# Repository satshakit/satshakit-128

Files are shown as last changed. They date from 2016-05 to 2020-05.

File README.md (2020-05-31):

<h1 style="font-family: courier;" align="center"> satshakit 128</h1>
<p align="center">
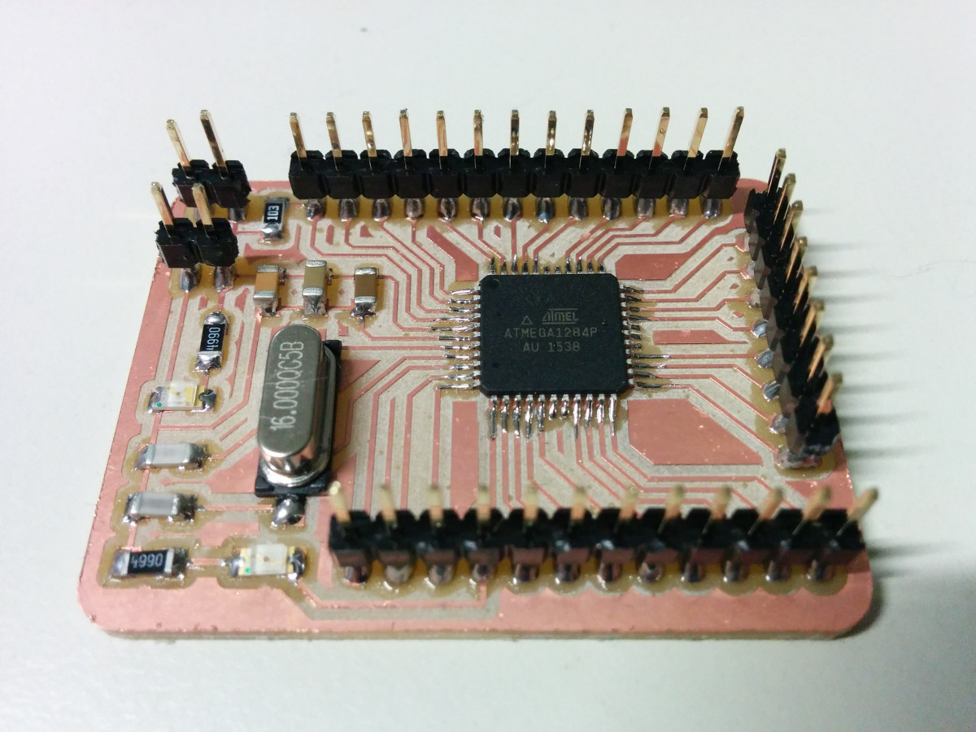
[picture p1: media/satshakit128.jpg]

<div align="center"><i>An improved & fabbable Arduino IDE/libraries compatible board.</i></div>
</p>  

What is satshakit?
--

satshakit is a **Arduino IDE  and libraries compatible**, fabbable and open source board, and also an improved version of [Fabkit](http://fabacademy.org/archives/2015/doc/projects/fabkit-0.4.html). 

Here you can find all of the satshakit boards: **[satshakit organization](https://github.com/satshakit)**.

satshakit 128
--

**satshakit 128** is microcontroller board designed around the **ATMega1284P** chip and it is suitable for complex scenarios in which is needed to have more flash and ram memory, but also the possibility to use 2 serial simultaneously.

In comparison with the other satshakits based on ATMega328P satshakit 128 has:

- **128k** flash memory instead of 32k
- **2 serials** instead of 1
- **16k of ram** instead of 2k
- **32 IO** pins instead of 23

Finally satshakit 128 is smaller than satshakit cnc and it costs **13 euro** each (much less for more).

Here you can have a look on **satshakit 128 board**:

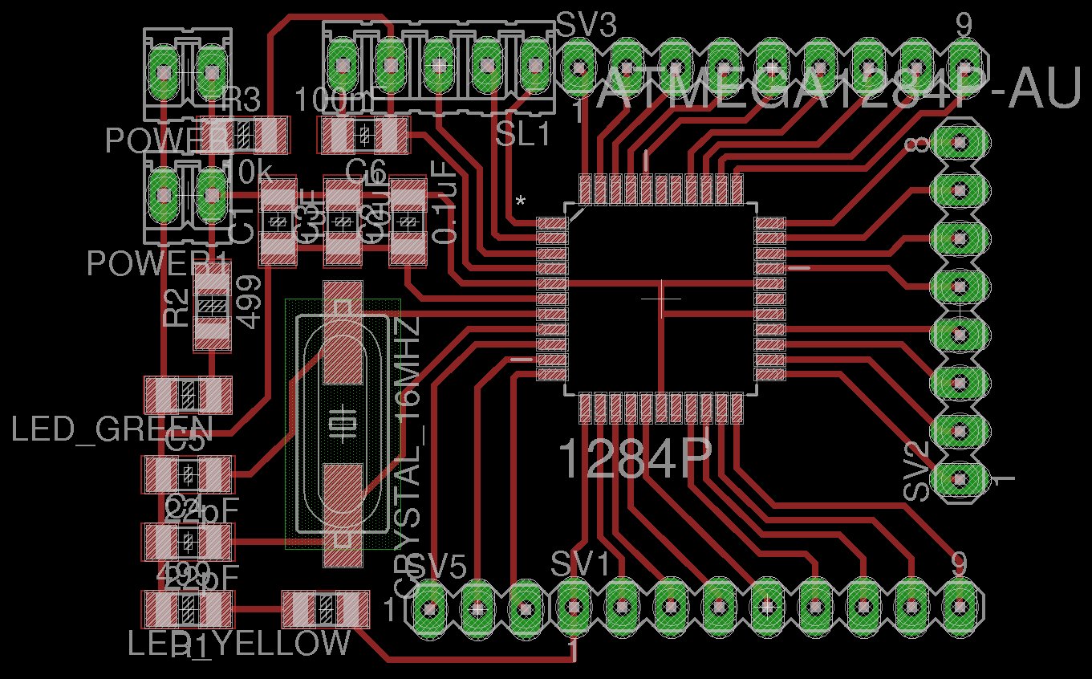
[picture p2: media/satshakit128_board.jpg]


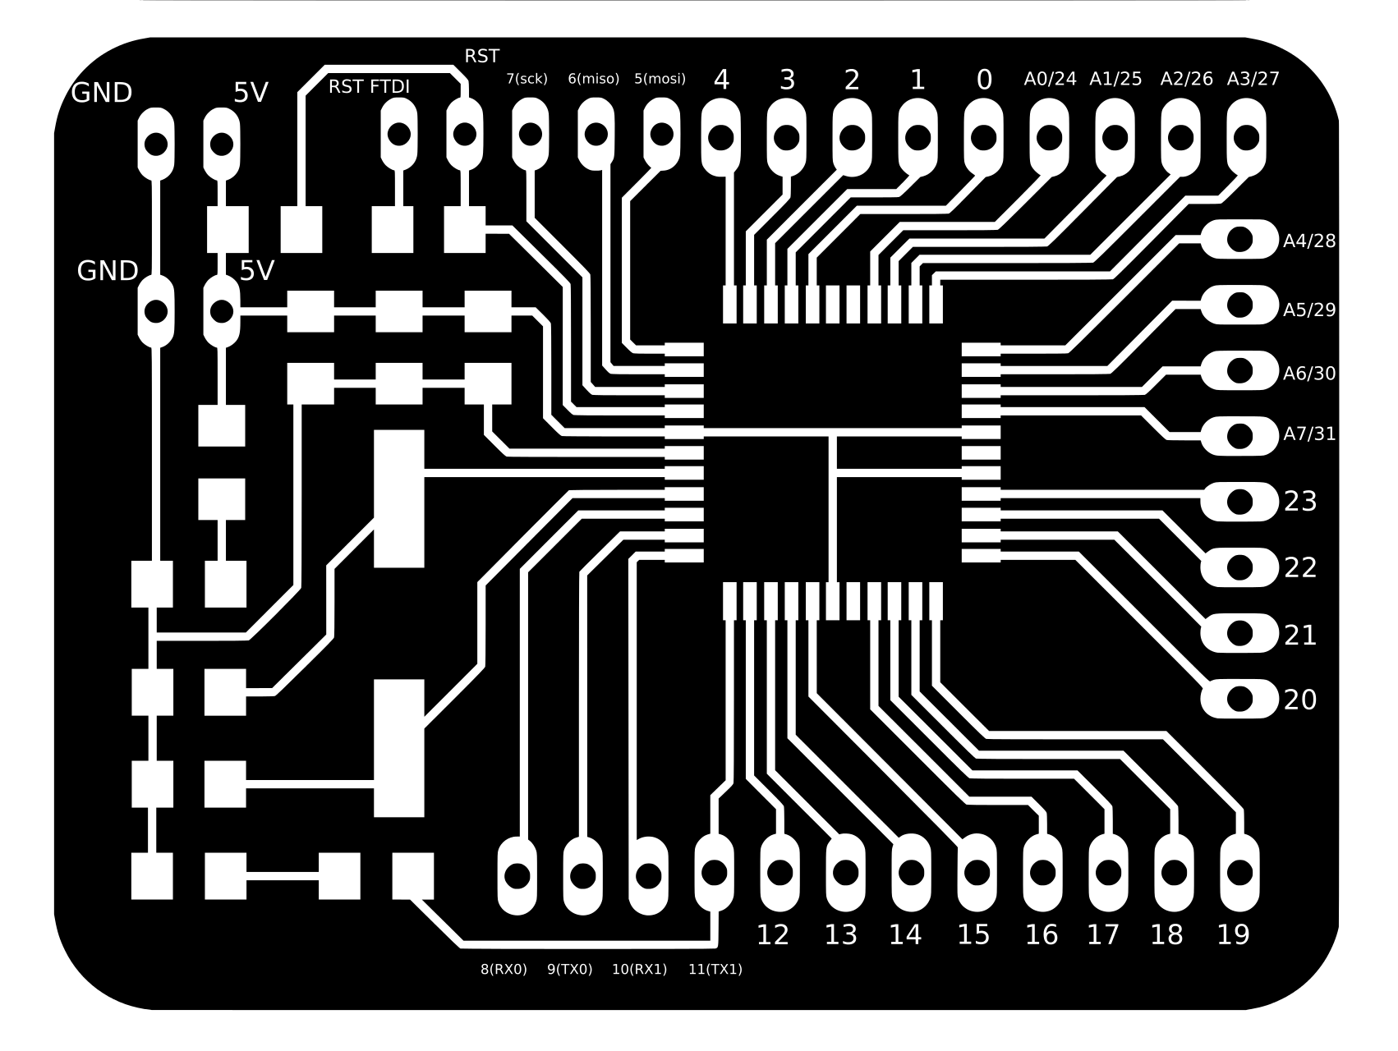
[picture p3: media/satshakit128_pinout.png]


**downloads (right click, download as)**

- [satshakit 128 svg](https://raw.githubusercontent.com/satshakit/satshakit-128/master/media/satshakit128.svg)
- [satshakit 128 internal png](https://raw.githubusercontent.com/satshakit/satshakit-128/master/media/satshakit128_internal.png)
- [satshakit 128 cut png](https://raw.githubusercontent.com/satshakit/satshakit-128/master/media/satshakit128_cut.png)
- [satshakit 128 schematic](https://raw.githubusercontent.com/satshakit/satshakit-128/master/eagle/satshakit128/satshakit128.sch)
- [satshakit 128 board](https://github.com/satshakit/satshakit-128/raw/master/eagle/satshakit128/satshakit128.brd)
- [satshakit 128 BOM Open Document](https://github.com/satshakit/satshakit-128/raw/master/docs/satshakit_128.ods)
- [satshakit 128 BOM Excel](https://github.com/satshakit/satshakit-128/raw/master/docs/satshakit_128.xlsx)

**media**

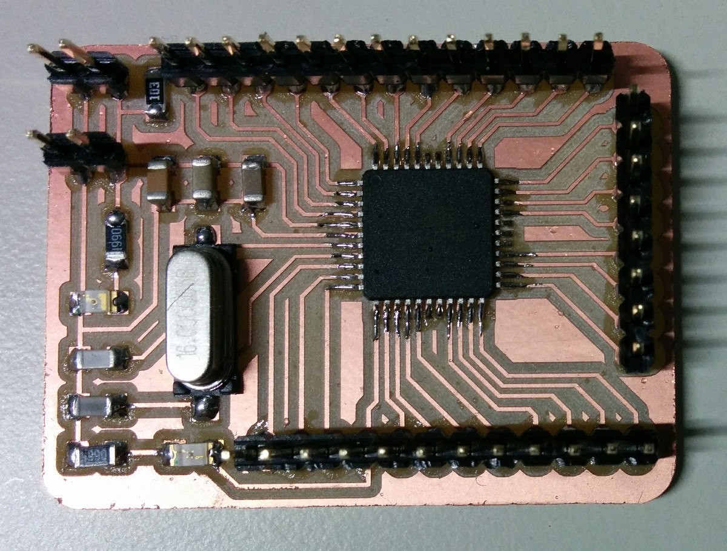
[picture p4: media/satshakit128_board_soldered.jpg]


satshakit 128 uploading bootloader:

<a href="http://www.youtube.com/watch?feature=player_embedded&v=KuCiwJ3c1IY
" target="_blank"></a>

satshakit 128 uploading blink:

<a href="http://www.youtube.com/watch?feature=player_embedded&v=X3d5tKupVwU
" target="_blank"></a>

Getting Started
--
A satshakit board is **very similar to an Arduino board**, thus is possible to use the Arduino IDE and its libraries. When you finish solder satshakit 128, you have to program it. If you want to use satshakit as an Arduino, you first need to **upload Arduino bootloader**. This will also set the ATmega1284P fuses. Before doing any programming you need to **patch your arduino IDE** using a specific set of files that will add the satshakit 128 as an available board to use. 

To add the support for satshakit 128 you can use the **[Mighty 1284P](https://github.com/JChristensen/mighty-1284p/tree/v1.6.3)**, that is provided in this repo inside the **[mighty-1284p folder](https://github.com/satshakit/satshakit-128/tree/master/mighty-1284p)**. 

To do so follow these steps:

1. **download** satshakit 128 repository
2. close **Arduino IDE** before doing anything
3. copy the folder named **mighty-1284p** inside the **Arduino IDE hardware folder**, **arduino-1.6.x/hardware/** in Linux, **Documents/Arduino/hardware** in MacOS 
4. open again the Arduino IDE
5. select **avr-developers.com pinouts 16MHz using Optiboot** board

Now you can use an Arduino as ISP to burn the bootloader and any Arduino sketch you want. To upload a program you connect **Arduino to the satshakit 128** as follows:

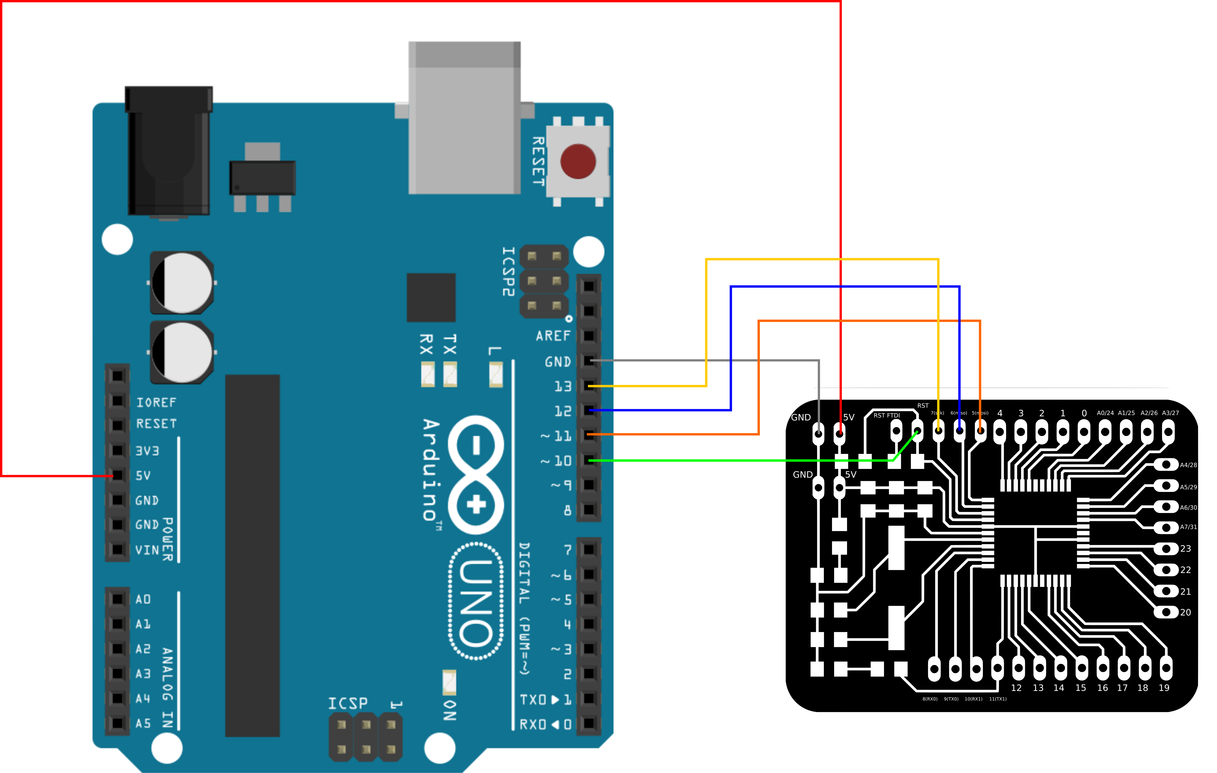
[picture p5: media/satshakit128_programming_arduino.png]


Once everything is connected, follow these steps to upload Arduino bootloader:

1. open Arduino IDE 
2. select proper programmer Arduino as ISP
3. select **avr-developers.com pinouts 16MHz using Optiboot** board
4. click on tools->Burn Bootloader

After you burnt the bootloader you can also use an **FTDI usb cable** to program the satshakit 128. Here is the connection schema to program the satshakit 128 using an FTDI cable:

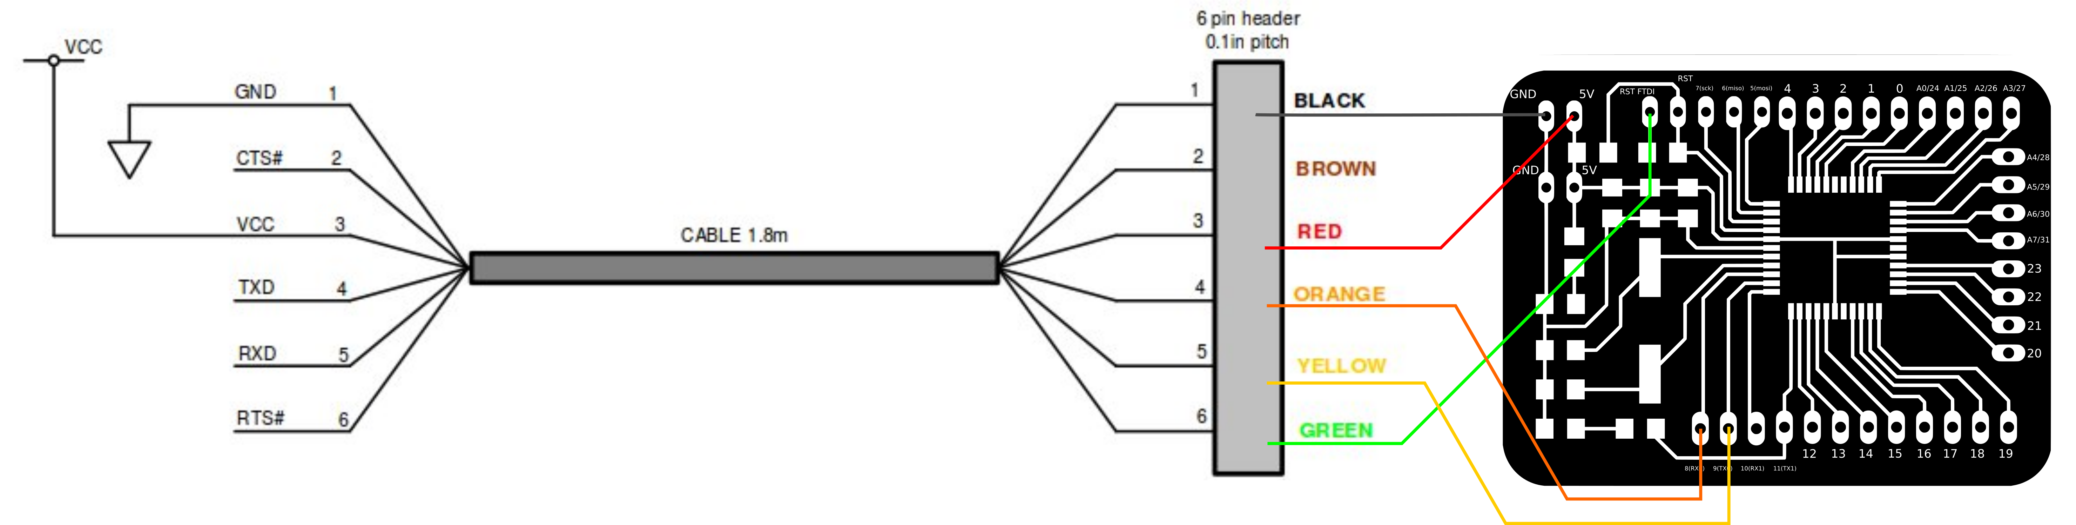
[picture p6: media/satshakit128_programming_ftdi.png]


Remember that if you try to program the satshakit 128 using an Arduino, then you will also delete the bootloader, losing the capability to be programmed using the FTDI cable. To hae back this possibility burn again the bootloader.

Here is the Arduino pinout of the satshakit 128:



What's in the repo
--
- **[docs](https://github.com/satshakit/satshakit-128/tree/master/docs)**: BOM files for Farnell
- **[egle projects](https://github.com/satshakit/satshakit-128/tree/master/eagle/satshakit128)**: eagle projects of satshakit
- **[media](https://github.com/satshakit/satshakit-128/tree/master/media)**: svg of satshakits, connections schemas, images for cnc milling machine and fiber laser cutter, other images

Authors
--

- Daniele Ingrassia

Contact
--

- **ingrassiada@gmail.com**
- **[linkedin](http://it.linkedin.com/in/danieleingrassia)**

Thanks
--

[Fablab Kamp-Lintfort](http://fablab.hochschule-rhein-waal.de/index.php/de/)<br />
Hochschule Rhein-Waal<br />
Friedrich-Heinrich-Allee 25, 47475 Kamp-Lintfort, Germany<br />
fablab@hochschule-rhein-waal.de

[Mighty 1284P](https://github.com/JChristensen/mighty-1284p/tree/v1.6.3)

License
--
This work is licensed under the terms of the open source license: Creative Commons Attribution-ShareAlike 4.0 International ([CC BY-SA 4.0](https://creativecommons.org/licenses/by-sa/4.0/)).

Disclaimer  
--

<div class="align-justify">
This hardware/software is provided "as is", and you use the hardware/software at your own risk. Under no circumstances shall any author be liable for direct, indirect, special, incidental, or consequential damages resulting from the use, misuse, or inability to use this hardware/software, even if the authors have been advised of the possibility of such damages.</div>

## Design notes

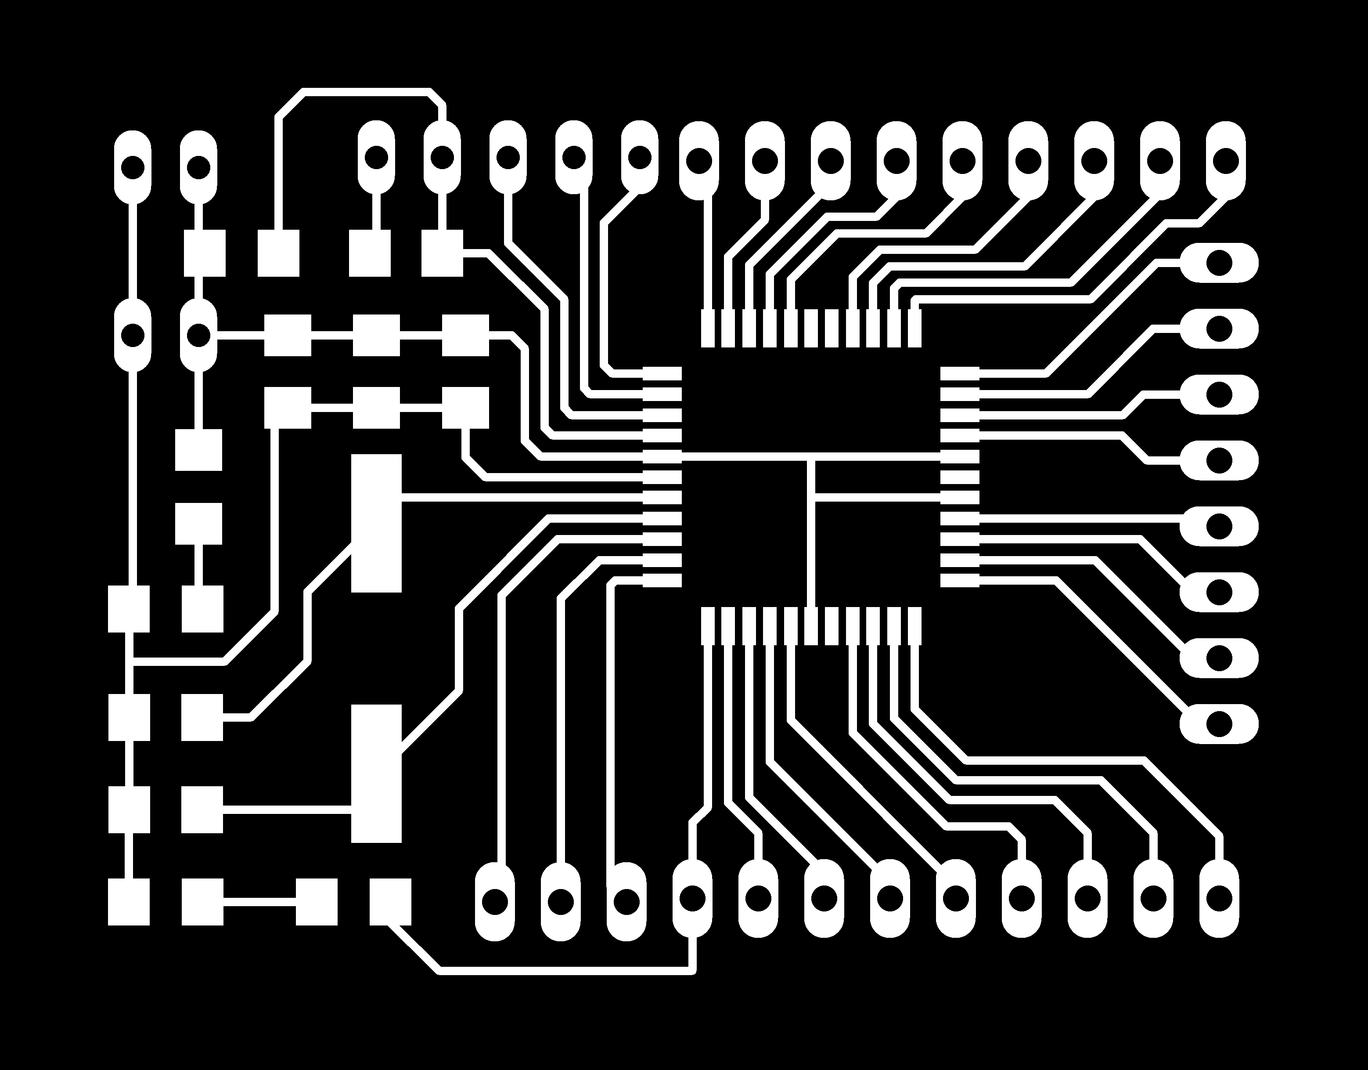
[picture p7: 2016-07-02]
media/satshakit128_internal.png

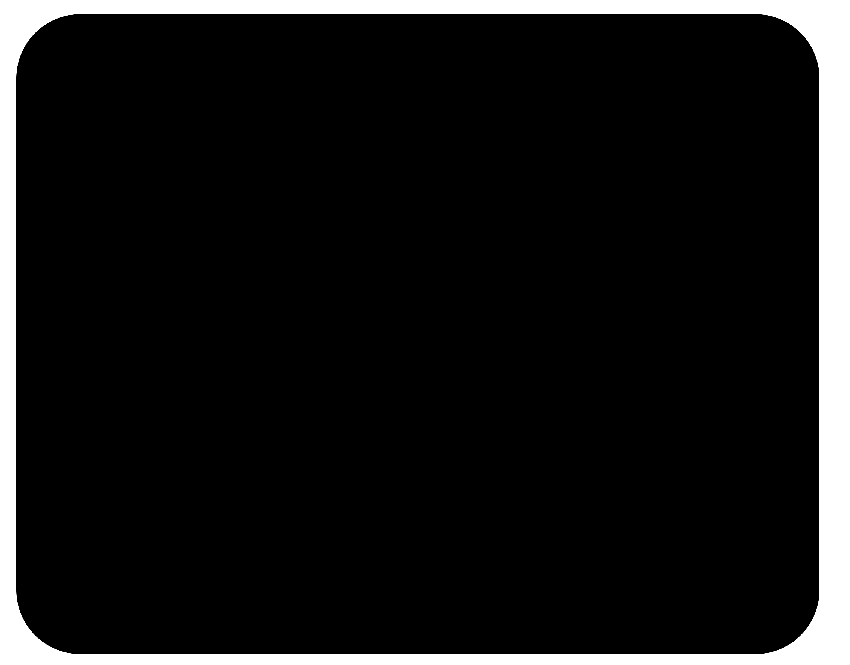
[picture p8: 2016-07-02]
media/satshakit128_cut.png

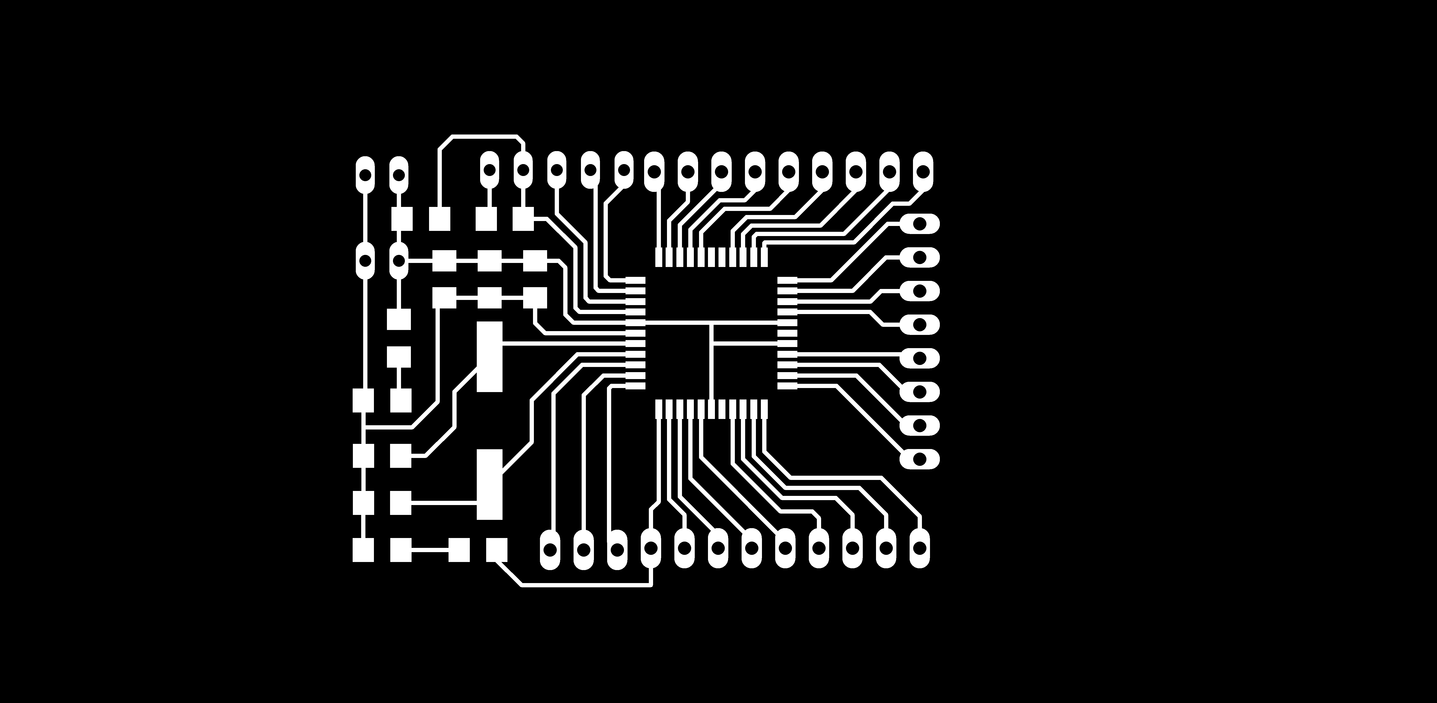
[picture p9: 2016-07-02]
media/satshakit128.png

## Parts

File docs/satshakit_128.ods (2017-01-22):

Value | Manufacturer Part No | Package | Description | FARNELL | Price € | Quantity | Min. Quantity Cost €
- | ATMEGA1284P-AU | TQFP-44 | microcontroller | 1715480 (http://it.farnell.com/atmel/atmega1284p-au/mcu-8bit-atmega-20mhz-tqfp-44/dp/1715480) | 7.56 | 1 | 7.56
16Mhz/18pF | MCRSD16000F183000RR | SMD 11.4 x 4.7 mm | crystal | 2395958 (http://it.farnell.com/multicomp/mcrsd16000f183000rr/crystal-16mhz-18pf-hc49-us-smd/dp/2395958) | 0.20 | 1 | 0.20
10K | ERJ8GEYJ103V | 1206 | resistor | 2057856 (http://it.farnell.com/panasonic-electronic-components/erj8geyj103v/resistore-1206-10k-5-0-25w/dp/2057856) | 0.03 | 1 | 0.26
22pF | MC1206N220J500CT | 1206 | capacitor | 2320891 (http://it.farnell.com/multicomp/mc1206n220j500ct/condens-mlcc-c0g-np0-22pf-50v/dp/2320891) | 0.05 | 2 | 0.47
10uF | MC1206X106K250CT | 1206 | capacitor | 2112753 (http://it.farnell.com/multicomp/mc1206x106k250ct/condensatore-mlcc-x5r-10uf-25v/dp/2112753) | 0.15 | 1 | 0.15
1uF | MC1206F105Z500CT | 1206 | capacitor | 1759455 (http://it.farnell.com/multicomp/mc1206f105z500ct/condensatore-mlcc-y5v-1uf-50v/dp/1759455) | 0.06 | 1 | 0.63
100nF | MC1206B104K500CT | 1206 | capacitor | 1759361 (http://it.farnell.com/multicomp/mc1206b104k500ct/condensatore-mlcc-x7r-100nf-50v/dp/1759361) | 0.04 | 2 | 0.70
green | MCL-S250GC | 1206 | green led | 1581232 (http://it.farnell.com/multicomp/mcl-s250gc/led-smd-1206-verde/dp/1581232) | 0.12 | 1 | 0.60
yellow | MCL-S250YC | 1206 | yellow led | 1581231 (http://it.farnell.com/multicomp/mcl-s250yc/led-smd-1206-giallo/dp/1581231) | 0.05 | 1 | 0.26
499 | CRCW1206499RFKEA | 1206 | resistor | 1470020 (http://it.farnell.com/vishay-draloric/crcw1206499rfkea/resistor-1206-499r-1/dp/1470020) | 0.03 | 2 | 0.28
- | 61304011021 | 2.54 mm | pin header | 2356192 (http://it.farnell.com/wurth-elektronik/61304011021/header-2-54mm-pin-tht-r-a-40way/dp/2356192) | 1.77 | 1 | 1.77
- | M20-9990246 | 2.54 mm | pin header | 1022247 (http://it.farnell.com/harwin/m20-9990246/header-diritta-2-54mm-1row-bifase/dp/1022247) | 0.07 | 1 | 0.65
 |  |  |  |  |  |  | Total cost
 |  |  |  |  |  |  | 13.54

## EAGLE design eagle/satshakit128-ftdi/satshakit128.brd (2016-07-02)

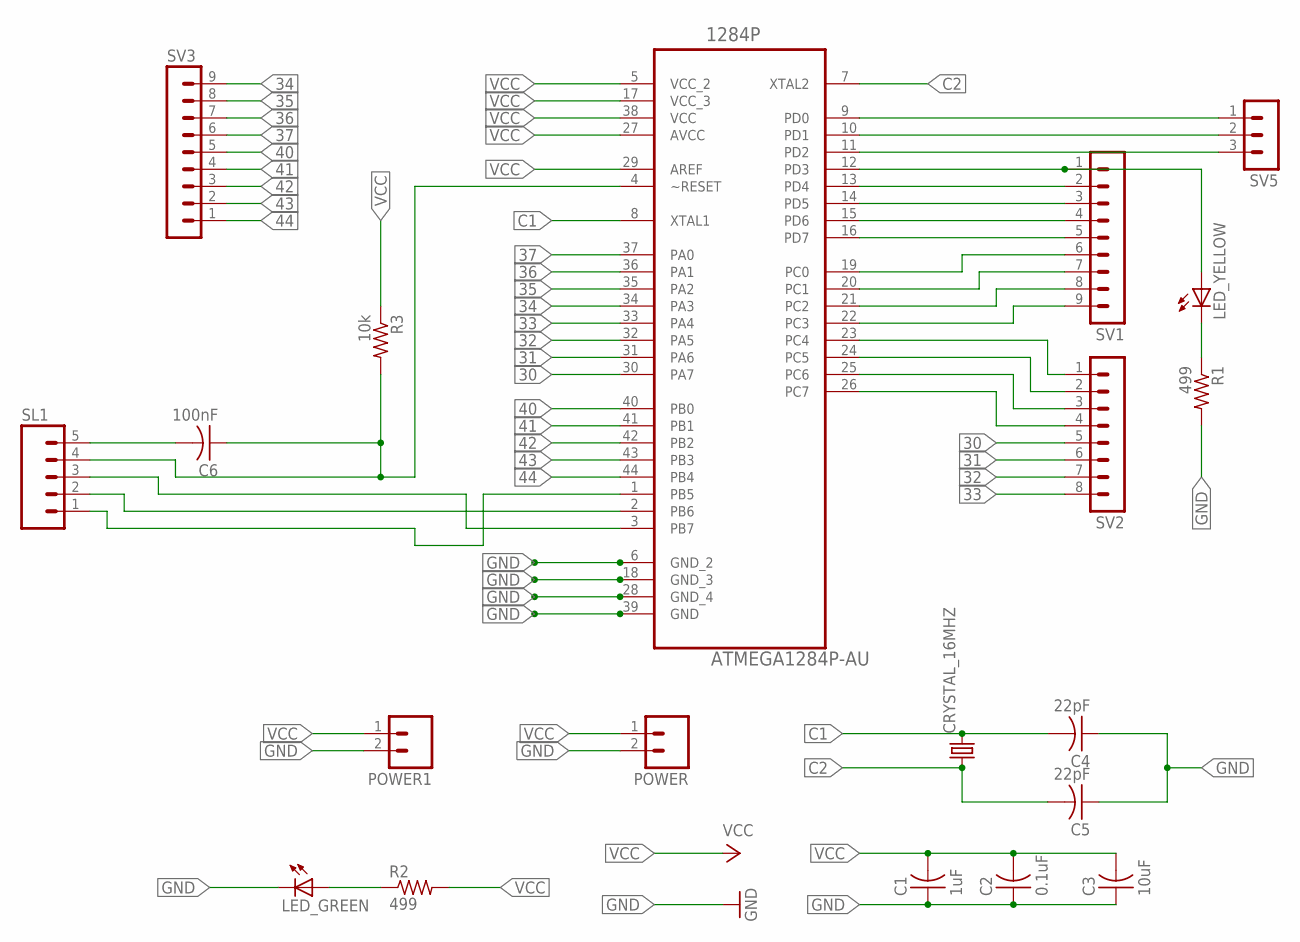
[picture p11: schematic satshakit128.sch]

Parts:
1284P: ATMEGA1284P-AU; QFP80P1200X1200X120-44N
C1: 1uF; C1206
C2: 0.1uF; C1206
C3: 10uF; C1206
C4, C5: 22pF; C1206
C6: 100nF; C1206
CRYSTAL_16MHZ: CRYSTALHC49UP; HC49UP
LED_GREEN: LED1206; 1206
LED_YELLOW: LED1206; 1206
POWER, POWER1: M02; 02P
R1, R2: 499; R1206
R3: 10k; R1206
SL1: M05; 05P
SV1, SV3: MA09-1
SV2: MA08-1
SV5: MA03-1

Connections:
30: 1284P.30 (PA7), SV2.5
31: 1284P.31 (PA6), SV2.6
32: 1284P.32 (PA5), SV2.7
33: 1284P.33 (PA4), SV2.8
34: 1284P.34 (PA3), SV3.9
35: 1284P.35 (PA2), SV3.8
36: 1284P.36 (PA1), SV3.7
37: 1284P.37 (PA0), SV3.6
40: 1284P.40 (PB0), SV3.5
41: 1284P.41 (PB1), SV3.4
42: 1284P.42 (PB2), SV3.3
43: 1284P.43 (PB3), SV3.2
44: 1284P.44 (PB4), SV3.1
C1: 1284P.8 (XTAL1), C4.2, CRYSTAL_16MHZ.2
C2: 1284P.7 (XTAL2), C5.2, CRYSTAL_16MHZ.1
GND: 1284P.6 (GND_2), C1.1, C2.1, C3.1, C4.1, C5.1, LED_GREEN.2 (C), POWER.2, POWER1.2, R1.2
unnamed: 1284P.19 (PC0), SV1.6
unnamed: 1284P.20 (PC1), SV1.7
unnamed: 1284P.16 (PD7), SV1.5
unnamed: 1284P.14 (PD5), SV1.3
unnamed: 1284P.13 (PD4), SV1.2
unnamed: 1284P.12 (PD3), LED_YELLOW.1 (A), SV1.1
unnamed: 1284P.11 (PD2), SV5.3
unnamed: 1284P.10 (PD1), SV5.2
unnamed: 1284P.9 (PD0), SV5.1
unnamed: 1284P.21 (PC2), SV1.8
unnamed: 1284P.22 (PC3), SV1.9
unnamed: 1284P.23 (PC4), SV2.1
unnamed: 1284P.24 (PC5), SV2.2
unnamed: 1284P.25 (PC6), SV2.3
unnamed: 1284P.26 (PC7), SV2.4
unnamed: 1284P.15 (PD6), SV1.4
unnamed: 1284P.3 (PB7), SL1.3
unnamed: 1284P.2 (PB6), SL1.2
unnamed: 1284P.1 (PB5), SL1.1
unnamed: 1284P.4 (~RESET), C6.1, R3.2, SL1.4
unnamed: LED_YELLOW.2 (C), R1.1
unnamed: LED_GREEN.1 (A), R2.1
unnamed: C6.2, SL1.5
VCC: 1284P.5 (VCC_2), 1284P.17 (VCC_3), 1284P.27 (AVCC), 1284P.29 (AREF), C1.2, C2.2, C3.2, POWER.1, POWER1.1, R2.2, R3.1

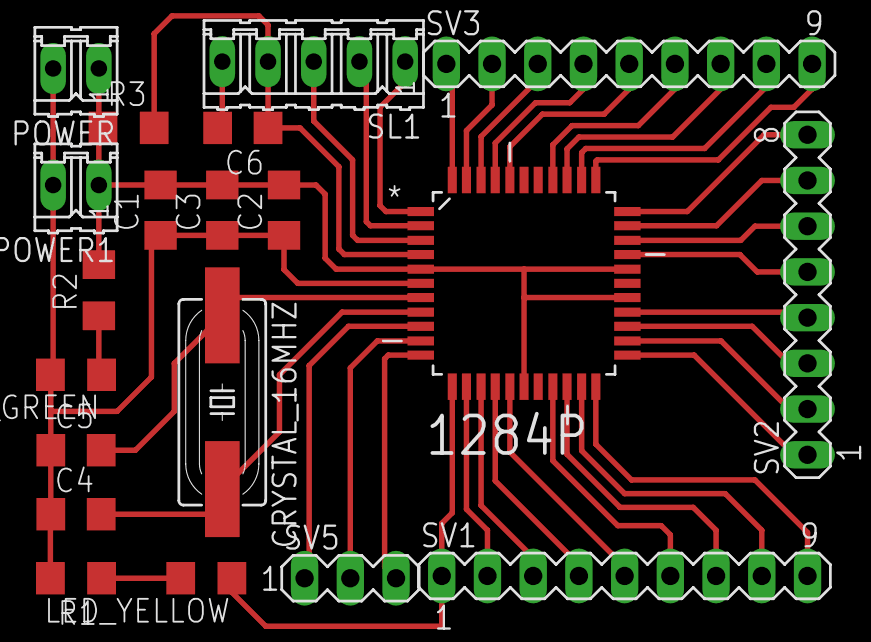
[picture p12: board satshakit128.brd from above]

Board: 2 copper layers, 20 parts (0 on the bottom side), 40 nets.

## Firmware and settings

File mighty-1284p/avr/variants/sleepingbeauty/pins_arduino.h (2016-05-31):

#ifndef Pins_Arduino_h
#define Pins_Arduino_h

#include <avr/pgmspace.h>

// Turn on this define when setting jumpers
// to use A4 and A5 for i2c vs analog pins
// See FootNote below for details
//#define _SB_BOARD_A4A5_I2C

// note: this define can be automatically be turned on through a menu entry
// in the boards.txt file by using the build extra_flags capability.
// i.e. using build.extra_flags=-D_SB_BOARD_A4A5_I2C

// ATMEL ATMEGA1284P on Sleeping Beauty board
//
//                            +---\/---+
//                (D 4) PB0 1 |        | 40 PA0 (D 21) AI 0
//                (D 5) PB1 2 |        | 39 PA1 (D 20) AI 1
//           INT2 (D 6) PB2 3 |        | 38 PA2 (D 19) AI 2
//       PWM/OC0A (D 7) PB3 4 |        | 37 PA3 (D 18) AI 3
//   PWM/OC0B/SS (D 10) PB4 5 |        | 36 PA4 (D 17) AI 4  *
//          MOSI (D 11) PB5 6 |        | 35 PA5 (D 16) AI 5  *
// PWM/OC3A/MISO (D 12) PB6 7 |        | 34 PA6 (D 30) AI 6
//  PWM/OC3B/SCK (D 13) PB7 8 |        | 33 PA7 (D 31) AI 7
//                      RST 9 |        | 32 AREF
//                     VCC 10 |        | 31 GND 
//                     GND 11 |        | 30 AVCC
//                   XTAL2 12 |        | 29 PC7 (D 14) 
//                   XTAL1 13 |        | 28 PC6 (D 15) 
//           RX0 (D 0) PD0 14 |        | 27 PC5 (D 27) TDI
//           TX0 (D 1) PD1 15 |        | 26 PC4 (D 26) TDO
//      INT0 RX1 (D 2) PD2 16 |        | 25 PC3 (D 25) TMS
//      INT1 TX1 (D 3) PD3 17 |        | 24 PC2 (D 24) TCK
//     PWM/OC1B (D 22) PD4 18 |        | 23 PC1 (D 28) SDA  *
//      PWM/OC1A (D 9) PD5 19 |        | 22 PC0 (D 29) SCL  *
//      PWM/OC2B (D 8) PD6 20 |        | 21 PD7 (D 23) PWM/OC2A
//                            +--------+
//
// *NOTE:
// Some boards contain a pair of jumpers which control A4 and A5 labeled pins.
// The Sleeping Beauty uses J4 and the BareBones boards use H5.
// The jumpers control which 1284 pins are physically connected to
// the pins labeled A4 and A5 on the board.
// When in the "deault"/"analog" or up position, the A4 and A5 labeled pins are
// connected to 1284 pins 35 and 35 which allows them to be used as analog
// inputs or digital pins using the A4 and A5 symbols in this header file.
//
// If the jumpers are in the "i2c" or down position, the A4 and A4 labeled
// pins are connected to 1284 pins 22 and 23 which is SCL and SDA.
// This allows the pins to be used for i2c or digital i/o but not for analog
// read operations.
// When jumpers are in this position, the symbols for A4 and A4 will not
// be correct unless the define above is also turned on.
//
/*
 *===========================================================================
 *
 * One of the major simplifications implemented by the Arduino core
 * libraries is the ability to reference the IO pins by a BOARD-defined "Pin
 * number" rather than needing to deal with the various IO register
 * addresses and bit numbers or masks that microcontrollers normally use to
 * access the external world.
 *
 * Of course, at some point the functions that use the "pin number" need to
 * translate that abstraction into the actual IO address and bits need to
 * manipulate them.  This is accomplished by core code in wiring_*.c that is
 * essentially identical for each major chip architecture (ie "avr"), and
 * this pins_arduino.h file that contains the specifics on a per-board or
 * per-chip basis.
 *
 * Various algorithms are possible, and there can be significant differences
 * depending on the capabilities of the architecture and chip being
 * used. (for example, a PIC32 has separate Set and Clear IO registers for
 * bitwise access, and an ARM CM3 might use "bit-banding")
 *

 * variants/<boarddesc>/pins_arduino.h contains the macros and/or tables
 * used to convert from Arduino-style "pin numbers" (0-13 on Uno, for
 * example) to the internal information necessary to perform operations on
 * those pins.
 *
 *===========================================================================
*/


/*
 * Most AVR-based Arduinos use tables built into flash (program) memory to
 * do the bulk of work, so we'll need the avr-libc definitions for dealing
 * with this additional address space.
 */

 
/*
 * Total number of digital pins.  This includes any analog pins that could
 * also be used for digital IO.
 */

#define NUM_DIGITAL_PINS            32

/*
 * Total number of Analog Input pins
 */

#define NUM_ANALOG_INPUTS           8


/*
 * Mapping macros
 * Some of these have to change depending on the board jumpers
 */
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

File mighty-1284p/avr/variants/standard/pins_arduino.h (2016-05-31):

#ifndef Pins_Arduino_h
#define Pins_Arduino_h

#include <avr/pgmspace.h>

// ATMEL ATMEGA1284P
//
//                       +---\/---+
//           (D 0) PB0  1|        |40  PA0 (AI 0 / D24)
//           (D 1) PB1  2|        |39  PA1 (AI 1 / D25)
//      INT2 (D 2) PB2  3|        |38  PA2 (AI 2 / D26)
//       PWM (D 3) PB3  4|        |37  PA3 (AI 3 / D27)
//    PWM/SS (D 4) PB4  5|        |36  PA4 (AI 4 / D28)
//      MOSI (D 5) PB5  6|        |35  PA5 (AI 5 / D29)
//  PWM/MISO (D 6) PB6  7|        |34  PA6 (AI 6 / D30)
//   PWM/SCK (D 7) PB7  8|        |33  PA7 (AI 7 / D31)
//                 RST  9|        |32  AREF
//                 VCC 10|        |31  GND 
//                 GND 11|        |30  AVCC
//               XTAL2 12|        |29  PC7 (D 23)
//               XTAL1 13|        |28  PC6 (D 22)
//      RX0 (D 8)  PD0 14|        |27  PC5 (D 21) TDI
//      TX0 (D 9)  PD1 15|        |26  PC4 (D 20) TDO
// RX1/INT0 (D 10) PD2 16|        |25  PC3 (D 19) TMS
// TX1/INT1 (D 11) PD3 17|        |24  PC2 (D 18) TCK
//      PWM (D 12) PD4 18|        |23  PC1 (D 17) SDA
//      PWM (D 13) PD5 19|        |22  PC0 (D 16) SCL
//      PWM (D 14) PD6 20|        |21  PD7 (D 15) PWM
//                       +--------+
//

/*
   PCINT15-8: D7-0  : bit 1
   PCINT31-24: D15-8  : bit 3
   PCINT23-16: D23-16 : bit 2
   PCINT7-0: D31-24   : bit 0
   */

#define MIGHTY_1284P_VARIANT "STANDARD"

#define NUM_DIGITAL_PINS            32
#define NUM_ANALOG_INPUTS           8
#define analogInputToDigitalPin(p)  ( (p) < NUM_ANALOG_INPUTS ? (p) + 24 : -1 )
#define digitalPinToAnalogPin(p)    ( (p) >= 24 && (p) <= 31 ? (p) - 24 : -1 )
#define analogPinToChannel(p)       ( (p) < NUM_ANALOG_INPUTS ? (p) : (p) >= 24 ? (p) - 24 : -1 )    //required macro for mighty-1284p core
#define digitalPinHasPWM(p)         ( (p) == 3 || (p) == 4 || (p) == 6 || (p) == 7 || (p) == 12 || (p) == 13 || (p) == 14 || (p) == 15 )

static const uint8_t SS   = 4;
static const uint8_t MOSI = 5;
static const uint8_t MISO = 6;
static const uint8_t SCK  = 7;

static const uint8_t SDA = 17;
static const uint8_t SCL = 16;
static const uint8_t LED_BUILTIN = 7;

static const uint8_t A0 = 24;
static const uint8_t A1 = 25;
static const uint8_t A2 = 26;
static const uint8_t A3 = 27;
static const uint8_t A4 = 28;
static const uint8_t A5 = 29;
static const uint8_t A6 = 30;
static const uint8_t A7 = 31;

#define digitalPinToPCICR(p)    ( (p) >= 0 && (p) < NUM_DIGITAL_PINS ? &PCICR : (uint8_t *)0 )
#define digitalPinToPCICRbit(p) ( (p) <= 7 ? 1 : (p) <= 15 ? 3 : (p) <= 23 ? 2 : 0 )
#define digitalPinToPCMSK(p)    ( (p) <= 7 ? &PCMSK1 : (p) <= 15 ? &PCMSK3 : (p) <= 23 ? &PCMSK2 : &PCMSK0 )
#define digitalPinToPCMSKbit(p) ( (p) % 8 )
// return associated INTx number for associated/valid pins,
// otherwise NOT_AN_INTERRUPT
#define digitalPinToInterrupt(p) \
	(\
	(p) == 10 ? 0 : \
	(p) == 11 ? 1 : \
	(p) == 2 ? 2 : \
	NOT_AN_INTERRUPT)


#define PA 1
#define PB 2
#define PC 3
#define PD 4

// specify port for each pin D0-D31
#define PORT_D0 PB
#define PORT_D1 PB
#define PORT_D2 PB
#define PORT_D3 PB
#define PORT_D4 PB
#define PORT_D5 PB
#define PORT_D6 PB
#define PORT_D7 PB
#define PORT_D8 PD
#define PORT_D9 PD
#define PORT_D10 PD
#define PORT_D11 PD
#define PORT_D12 PD
#define PORT_D13 PD
#define PORT_D14 PD
#define PORT_D15 PD
#define PORT_D16 PC
#define PORT_D17 PC
#define PORT_D18 PC
#define PORT_D19 PC
#define PORT_D20 PC
#define PORT_D21 PC
#define PORT_D22 PC
#define PORT_D23 PC
#define PORT_D24 PA
#define PORT_D25 PA
#define PORT_D26 PA
#define PORT_D27 PA
#define PORT_D28 PA
#define PORT_D29 PA
#define PORT_D30 PA
#define PORT_D31 PA

// specify port bit for each pin D0-D31
#define BIT_D0 0
#define BIT_D1 1
#define BIT_D2 2
#define BIT_D3 3
#define BIT_D4 4
#define BIT_D5 5
#define BIT_D6 6
#define BIT_D7 7
#define BIT_D8 0
#define BIT_D9 1
#define BIT_D10 2
#define BIT_D11 3
#define BIT_D12 4
#define BIT_D13 5
#define BIT_D14 6
#define BIT_D15 7
#define BIT_D16 0
#define BIT_D17 1
#define BIT_D18 2
#define BIT_D19 3
#define BIT_D20 4
#define BIT_D21 5
#define BIT_D22 6
#define BIT_D23 7
#define BIT_D24 0
#define BIT_D25 1
#define BIT_D26 2
#define BIT_D27 3
#define BIT_D28 4
#define BIT_D29 5
#define BIT_D30 6
#define BIT_D31 7

// macro equivalents of PROGMEM arrays port_to_mode_PGM[] etc. below
#define PORT_TO_MODE(x) (x == 1 ? &DDRA : (x == 2 ? &DDRB : (x == 3 ? &DDRC : (x == 4 ? &DDRD : NOT_A_PORT)))) 
#define PORT_TO_OUTPUT(x) (x == 1 ? &PORTA : (x == 2 ? &PORTB : (x == 3 ? &PORTC : (x == 4 ? &PORTD : NOT_A_PORT))))
#define PORT_TO_INPUT(x) (x == 1 ? &PINA : (x == 2 ? &PINB : (x == 3 ? &PINC : (x == 4 ? &PIND : NOT_A_PORT)))) 
 
#ifdef ARDUINO_MAIN
// these arrays map port names (e.g. port B) to the
// appropriate addresses for various functions (e.g. reading
// and writing)
const uint16_t PROGMEM port_to_mode_PGM[] =
{
  NOT_A_PORT,
  (uint16_t) &DDRA,
  (uint16_t) &DDRB,
  (uint16_t) &DDRC,
  (uint16_t) &DDRD,
};
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

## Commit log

2016-05-31 first satshakit128 commit
    [pins.ods, satshakit128.brd, satshakit128.sch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]
2016-07-02 added a new version that is possible to proigram using only the FTDI
    [satshakit128.brd, satshakit128.sch]
2017-01-22 added the 2nd reset pin to enable the FTDI programming
    [satshakit128.brd, satshakit128.sch, satshakit_128.ods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]
2017-01-22 removed the satshakit boards list
